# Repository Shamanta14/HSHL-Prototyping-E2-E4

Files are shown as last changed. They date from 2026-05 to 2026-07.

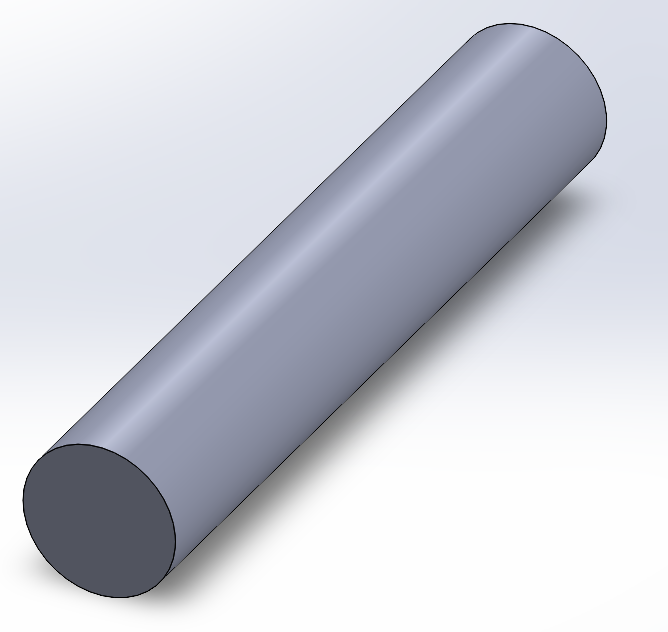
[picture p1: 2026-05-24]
CAD_Designs /CAD_Designs/GearMotor_Holder/Locking_Pin.png

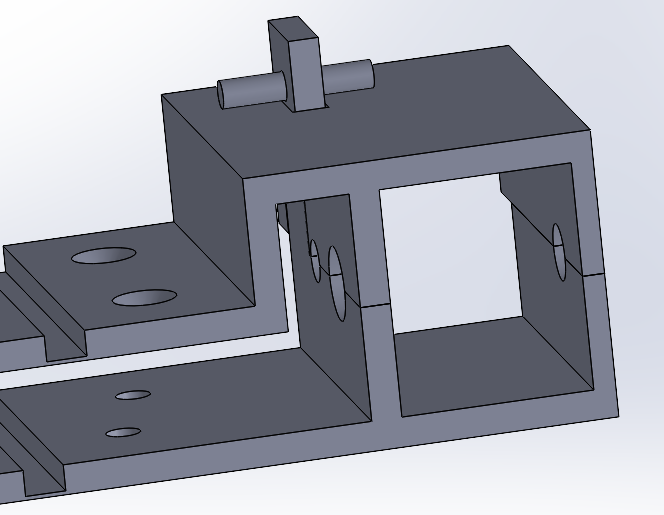
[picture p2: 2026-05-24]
CAD_Designs /CAD_Designs/GearMotor_Holder/Assembly_Motor_Holder.png

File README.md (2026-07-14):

# HSHL-Prototyping-E2-E4
Design and construction of an autonomous vehicle.

## Aim and objective 
The goal of this project is to design and prototype an autonomous robot capable of:
- Following a predefined track using line detection sensor.
- Detecting and avoiding obstacles in real time .
- Operating on a battery‑powered system with PWM speed control.

  ## System overview
  The autonomous robot integrates multiple subsystems:
- **IR sensors** detect line and provide feedback for track following control.
- **Ultrasonic sensors** measure distance to obstacles and trigger avoidance maneuvers when necessary.
- **The motor driver** controls direction and speed using PWM signals.
- Power is supplied by a 11,1 battery through a push on/off switch.

## Bill of material 

| Component | Quantity |
|---|---|
| Arduino Uno | 1 |
| Hobby Gearmotor | 2 |
| IR Sensor | 2 |
| Ultrasonic Sensor (4‑pin) | 2 |
| 9V Battery | 1 |
| Slide Switch | 1 |

### Repository Structure

| Folder Name | Description |
|---|---|
| CAD_Designs/CAD_Designs  | Contains 3D models and mechanical design files for the robot chassis. |
| Main_Robot_Project | Includes Arduino code, wiring diagrams, and main logic implementation. |
| Sensors_Datasheets | Datasheets for IR and Ultrasonic sensors used in the project. |
| Sensors_Testing | Test results and calibration data for sensor performance. |
| System&UML_diagrams | UML diagrams and system architecture documentation. |
| README.md | Project overview and documentation. |

## Contributors 
Project by Team E2-E4
-
-
-
-
Hochschule Hamm Lippstadt

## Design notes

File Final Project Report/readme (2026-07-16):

## Project Report

The complete project report documents the design, implementation, testing, and evaluation of the autonomous vehicle.

The report covers the following main topics:

- Background, problem statement, project goals, and constraints
- System design and engineering approach
- System architecture, data flow, and UML diagrams
- Hardware components, electrical connections, and mechanical design
- Software architecture, PID control, and obstacle avoidance
- Simulation, testing, verification, and performance evaluation
- Challenges, current limitations, and future improvements
- Team contributions, conclusion, and lessons learned

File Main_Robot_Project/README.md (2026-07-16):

## Track following robot.
-> Battery-powered system with a slide switch.

-> PWM (Pulse Width Modulation) Speed Control using analogWrite() for the Gearmotor speed.

-> Two Ultra Sonic Sensor detects the presence of an obstacle within a specified threshold distance.

## Detection threshold 
   Any object detected at or below the specified threshold distance will be considered as "Detected".

   Else "Not Detected".

->The Two IR sensor detect the presence of the track.

## IR sensor reading 

   LOW (0) when detecting black track

   HIGH (1) when detecting white surface

## System Behaviour 

-> The robot moves forward only when it is on the track and there is no obstacle ahead.

-> If the robot moves away from the track, it automatically self-corrects its position

   and continues moving along the track.

-> If an obstacle is detected ahead within the threshold distance, the robot stops moving.

## Bill of material

| Component |Quantity |
|---|---|
| Arduino Uno | 1 |
| Hobby Gearmotor | 2 |
| IR Sensor | 2 |
| Ultrasonic Sensor (4‑pin) | 2 |
| 9V Battery | 1 |
| Push on/off Switch | 1 |

 ## Repository Structure

| Folder/File | Description |
|---|---|
| Assembled Parts | Mechanical assembly files for robot chassis |
| Motor Driver | Code for PWM motor control |
| Sensors Code Function | Functions for IR,ultrasonic sensors and motor. |
| Tinkercad_circuitwiring  | Circuit wiring diagrams |
| Code.cc | Main Arduino logic implementation |
| Pin_Connections.h | Pin mapping for sensors and motors |
| README.md | Project documentation |

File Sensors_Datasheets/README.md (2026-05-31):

# Components Datasheets

This folder contains the datasheets for all major electronic components used in the autonomous robot project.  
Each datasheet provides essential technical information such as:

- Electrical characteristics  
- Pin configurations  
- Operating voltages  
- Timing diagrams  
- Mechanical dimensions  
- Usage guidelines  

These documents are critical for correct system design, wiring, and integration of the robot’s hardware components.

## Repository Structure

| File/Folder Name | Description |
|---|---|
| Arduino_Uno_Datasheet.PDF | Datasheet for Arduino Uno microcontroller board |
| IR_Sensor-Datasheet.pdf | Datasheet for IR sensor used in line detection |
| L298N Motor Driver Datasheet.pdf | Datasheet for L298N motor driver IC |
| Ultra_Sonic_Sensor(4-pins)_Datasheet.pdf | Datasheet for HC‑SR04 ultrasonic distance sensor |
| README | Documentation describing component datasheets usage |

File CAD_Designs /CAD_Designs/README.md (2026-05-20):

## CAD Designs-Prototype 

This folder contains all 3D‑designed holders required for the HSHL Prototyping project.
Each holder was modeled with correct tolerances, print‑ready geometry, and mounting features suitable for laser‑cut or 3D‑printed chassis integration.

## Included components 
## Motor holder 
-Designed to secure the DC motor firmly during motion.

-Includes side walls and a base slot for stability.

-Mounting holes added for attachment to the chassis.

-Clearance added to prevent vibration and friction.

## IR-sensor holder 
-Tolerances applied (0.3–0.5 mm) to ensure smooth insertion.

-Side guides prevent sensor wobbling.

-Front opening allows unobstructed IR transmission.

## UR-sensor holder 
-Dual‑eye cutouts for the ultrasonic transducers.

-PCB support rails included to hold the board in place.

-Mounting tabs added for chassis attachment.

-Fully closed geometry for 3D printing.

## Battery and Breadboard Holder 
-Compartment designed to hold the battery pack securely.

-Separate platform for the mini breadboard.

-Cable‑routing slots included for clean wiring.

-Reinforced walls for durability.

## Tools Used 
- Solid was used to design the parts.
  
- Bambu studio used to generate the simulation for the 3D printing

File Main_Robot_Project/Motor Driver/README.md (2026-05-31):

Tinkercad Motor Driver Test:

Testing the following components together:

-> Two gear motors -> One slide switch -> One Motor Driver(L293D)

The system is powered using a 9V battery with a slide switch for power control.

The Enable1&2 and Enable3&4 pins of motor driver are connected to Arduino pins 6 and 9. Because they are PWM pins which can be used to control the motor speed.

The Input pins 1,2,3 and 4 are connected to Arduino pins 3,2,12 and 13 respectively. These Input pins can be used to control the motor direction.

The purpose of this testing is to verify that the motor driver can control the speed and direction of the gear motors, as well as stop and start them flexibly.

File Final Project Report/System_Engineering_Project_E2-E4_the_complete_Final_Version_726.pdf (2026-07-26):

## Design and Development of an Autonomous Mobile Robot with PID-Based Line Following and Obstacle Avoidance

Xintong Feng, Shamanta Islam, Paula Cho, Elvis-Ledoux

Systems Engineering Project Group E2–E4
Hochschule Hamm-Lippstadt (HSHL)

Abstract— This project presents the design and development of an autonomous mobile robot capable of line following and obstacle avoidance. The system integrates an Arduino Uno, infrared sensors, ultrasonic sensors, DC motors, and PID-based control to achieve reliable navigation on a predefined track. The robot was designed, simulated, assembled, and tested to evaluate sensor performance, motor control, and overall system reliability. Experimental results demonstrate successful line tracking, obstacle detection, and autonomous manoeuvring, while highlighting opportunities for future improvement in adaptive obstacle avoidance.

Keywords—Autonomous mobile robot, line following, obstacle avoidance, PID control, infrared sensors, ultrasonic sensors, Arduino Uno.

### 1. Introduction and Objectives

### 1.1 Background

Autonomous vehicles have become an important topic in robotics because they can perform tasks with little or no human intervention. One common example is a line-following robot, which uses sensors to detect and follow a predefined path. Such robots are widely used in warehouses, factories, and automated production systems to transport materials efficiently while reducing manual work. Because of their practical applications, line-following robots are often used in educational projects to study embedded systems, sensor integration, and motor control.

### 1.2 Problem Statement

Line-following robots often struggle to maintain accurate tracking, especially during sharp turns, under inconsistent lighting conditions, or when unexpected obstacles appear on the path. This project addresses the challenge of designing a small autonomous vehicle that can reliably follow a black line while detecting obstacles, performing avoidance manoeuvres, and returning to the original track.

### 1.3 Project Goal

The goal of this project is to design and build an autonomous mobile robot capable of navigating a predefined track while demonstrating basic autonomous behaviour through line following and obstacle avoidance.
The specific objectives of this project are:
- Design and construct an autonomous vehicle.
- Follow a predefined black line.
- Detect obstacles.
- Perform an obstacle-avoidance manoeuvre and safely return to the original track.
- Control the DC motors.
- Integrate all hardware and software components into one complete system.
- Test and evaluate the prototype under different operating conditions.

### 1.4 Project Constraints

- The robot must be built using low-cost components, including an Arduino Uno R3, IR sensors, ultrasonic sensors, and simple DC motors.
- The system operates on battery power, which limits runtime and requires efficient motor control.
- IR and ultrasonic sensors have limited range and accuracy, especially under varying lighting and surface conditions.
- The robot must navigate a predefined track containing curves and obstacles using PWM and PID-based control.
- Development and testing must be completed within the course timeframe.

### 2. System Design and Engineering Approach

### 2.1 Design Approach

The system was designed using a top-down modular approach. We first defined the overall system architecture and then decomposed it into four major subsystems. Each subsystem was assigned a specific functional responsibility to ensure a clear structure, straightforward integration, and reliable operation.

### 2.2 System Architecture Overview

The autonomous robot consists of four interconnected subsystems:
- Power Subsystem
- Sensor Subsystem
- Control Subsystem
- Motor Subsystem

The functional requirements of each subsystem are listed below.
- Power Subsystem: Supplies stable voltage and current.
- Sensor Subsystem: Detects environmental changes and generates measurement signals.
- Control Subsystem: Processes sensor measurements and produces control commands.
- Motor Subsystem: Converts control commands into mechanical motion.

Together, these subsystems fulfil the functional requirements of the autonomous robot, with each subsystem performing a specific role in the overall operation of the system.

### 2.3 System Data Flow

The autonomous robot operates through a continuous flow of electrical signals and power between the four subsystems.
- Sensor Subsystem → Control Subsystem

– IR sensors send digital signals indicating whether the robot is on the line.
– Ultrasonic sensors send distance measurements for obstacle detection.
- Control Subsystem → Motor Subsystem

– The Arduino processes sensor inputs and determines whether the robot should move forward, turn, stop, or

avoid obstacles.
– PWM signals and direction commands are generated for the motor driver.
- Motor Subsystem → Mechanical Motion

– The motor driver amplifies the control signals and drives the DC motors.
– The motors perform the required movements (forward, left, right, and stop).
- Power Subsystem → All Subsystems

– The battery supplies stable voltage to the Arduino, sensors, motor driver, and motors.
– Continuous power enables sensing, control, and actuation.

This data flow enables all subsystems to operate together, allowing the robot to achieve reliable line following and obstacle avoidance.

### 3. System and UML Diagrams

To support the development of the autonomous vehicle, a set of system and UML diagrams was created to model the architecture, behaviour, and interactions within the system. These diagrams provide a structured understanding of how the robot operates, how its subsystems communicate, and how the control logic responds to sensor inputs.

### 3.1 Block Definition Diagram

Figure 1 shows the main hardware subsystems of the robot and their relationships. The system consists of four main parts: the power supply, sensing, control, and driving subsystems. The sensing subsystem includes the IR and ultrasonic sensors, the control subsystem contains the Arduino Uno, and the driving subsystem consists of the motor driver and DC motors. The wheel assembly is shown separately as a mechanical component.

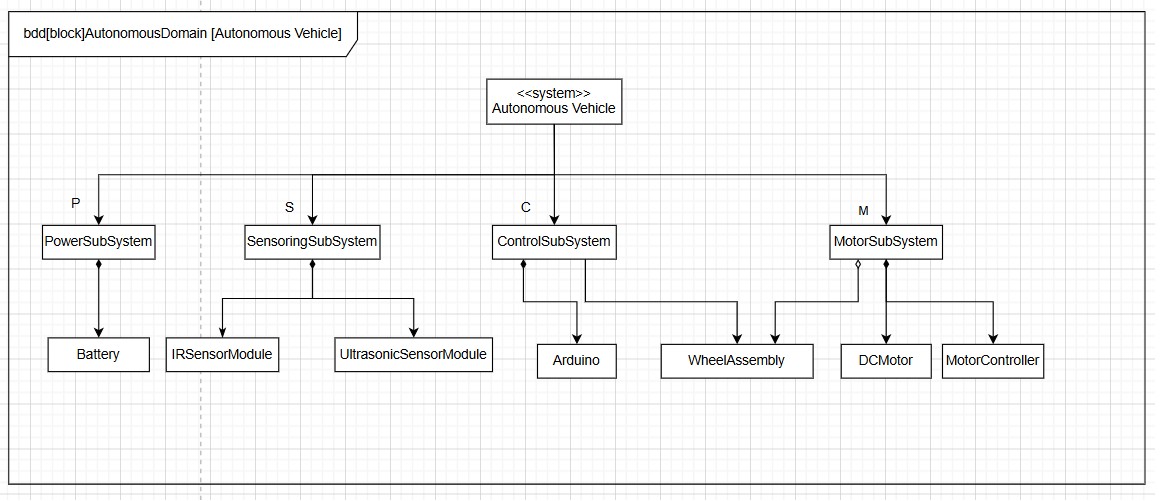
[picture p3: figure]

Fig. 1. Block Definition Diagram

### 3.2 Internal Block Diagram

Fig. 2 shows the internal connections between the robot subsystems. The power subsystem supplies the Arduino Uno, while the sensing subsystem contains the IR and ultrasonic sensors connected to it. Based on the sensor data, the Arduino sends control commands to the motor driver, which drives the DC motors. The diagram shows how power, sensor data, and control signals flow through the system.

### 3.3 Activity Diagram

Fig. 3 shows the swimlane-based workflow of the autonomous vehicle. It is divided into four swimlanes: IR sensors, ultrasonic sensors, controller, and drive motors.
The swimlanes show which system component performs each activity, while the decision nodes show how the controller selects PID line following, obstacle bypass, or a 180-degree

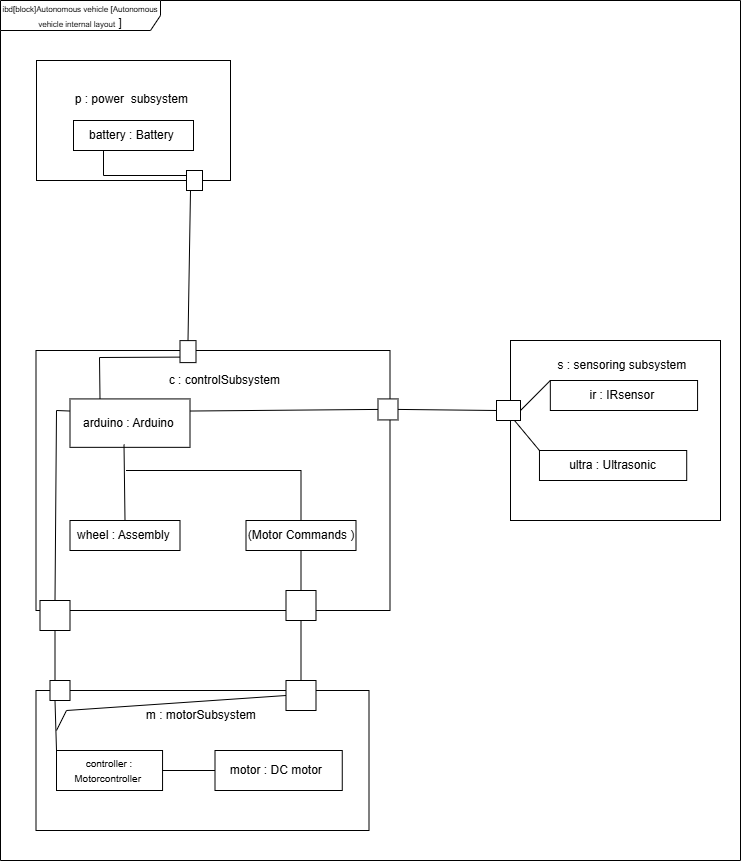
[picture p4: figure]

Fig. 2. Internal Block Diagram

U-turn. The arrows show the order of the activities and the flow between the four system components.

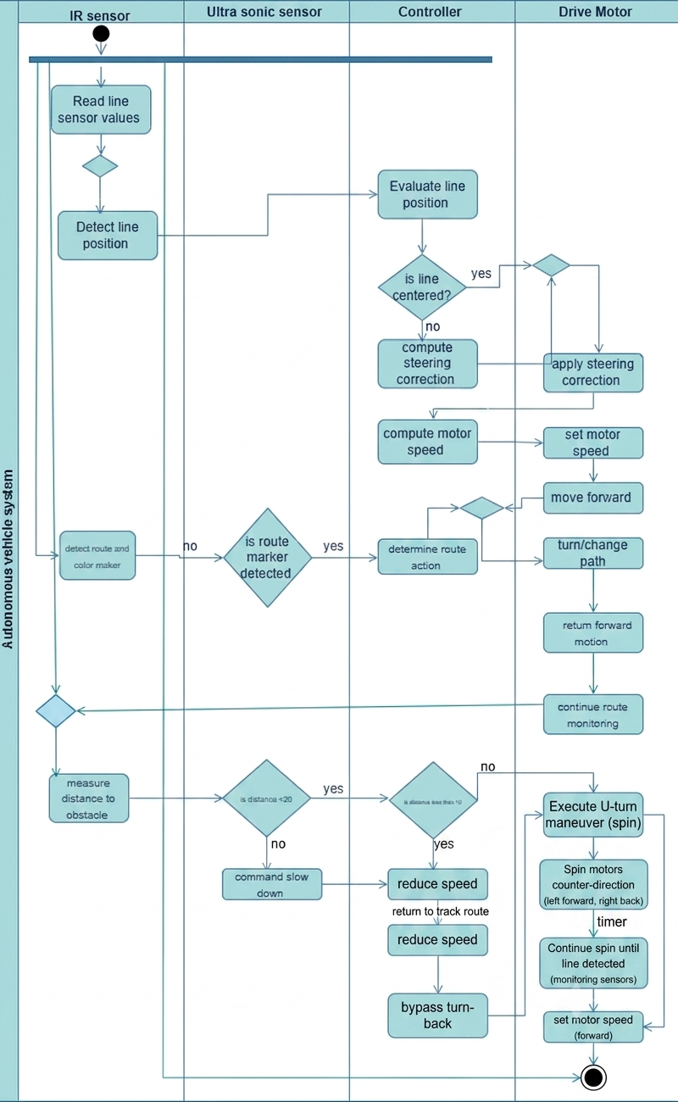
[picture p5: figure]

Fig. 3. Activity Diagram

### 3.4 Sequence Diagram

Fig. 4 shows the sequence diagram of the autonomous vehicle, including five lifelines: the IR sensors, Ultrasonic sensors, Arduino, motor driver, and DC motors. The messages are arranged from top to bottom in time order. The alt frame shows three cases: normal line following, first-obstacle bypass, and second-obstacle 180-degree U-turn. The loop frame shows that the process repeats continuously.

### 3.5 Use Case Diagram

Fig. 5 shows the main functions of the autonomous vehicle control software. The diagram includes line following, route navigation, obstacle avoidance, stopping, and performing a U-turn. The include and extend relationships show how these functions are connected and under which conditions they are

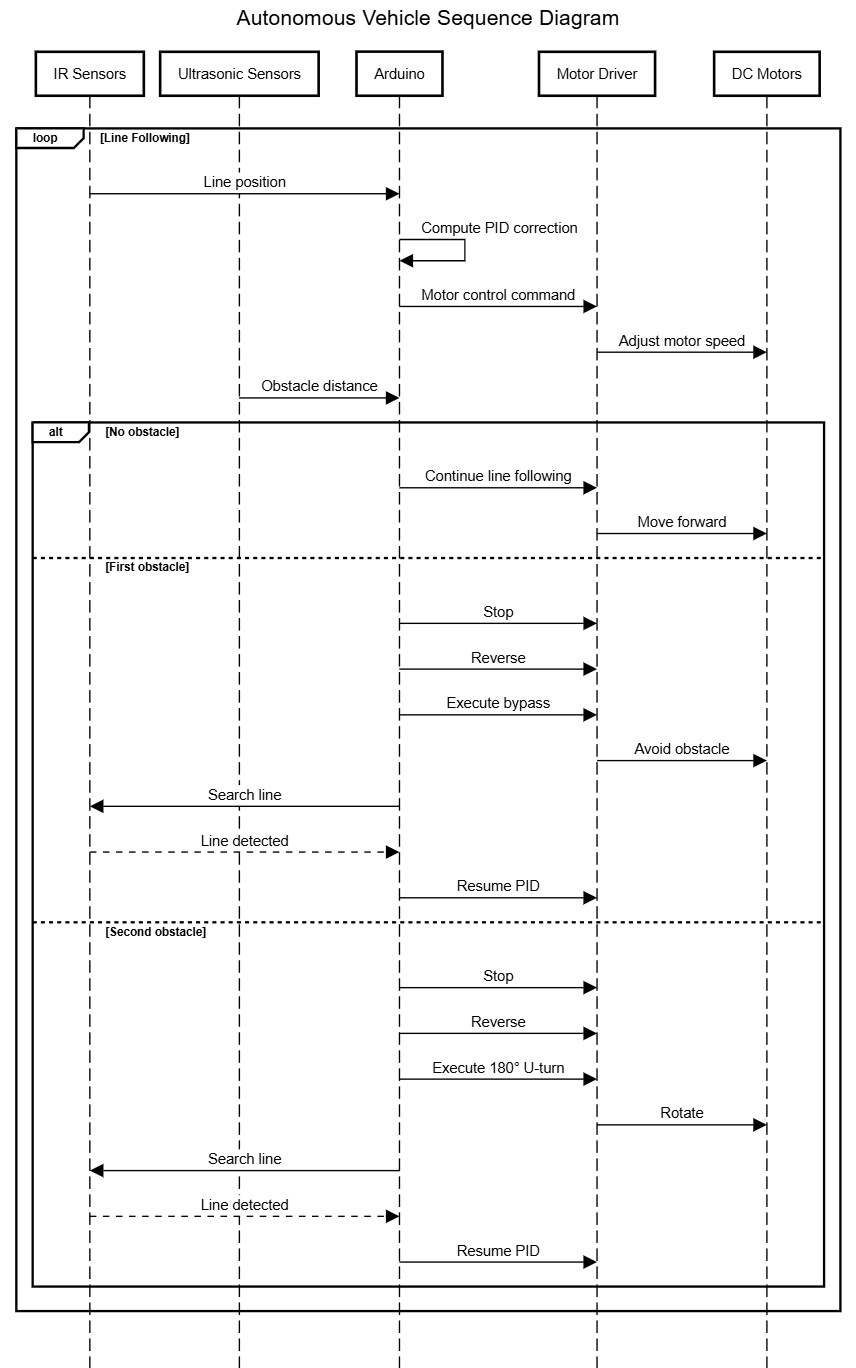
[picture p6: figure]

Fig. 4. Sequence Diagram

executed.

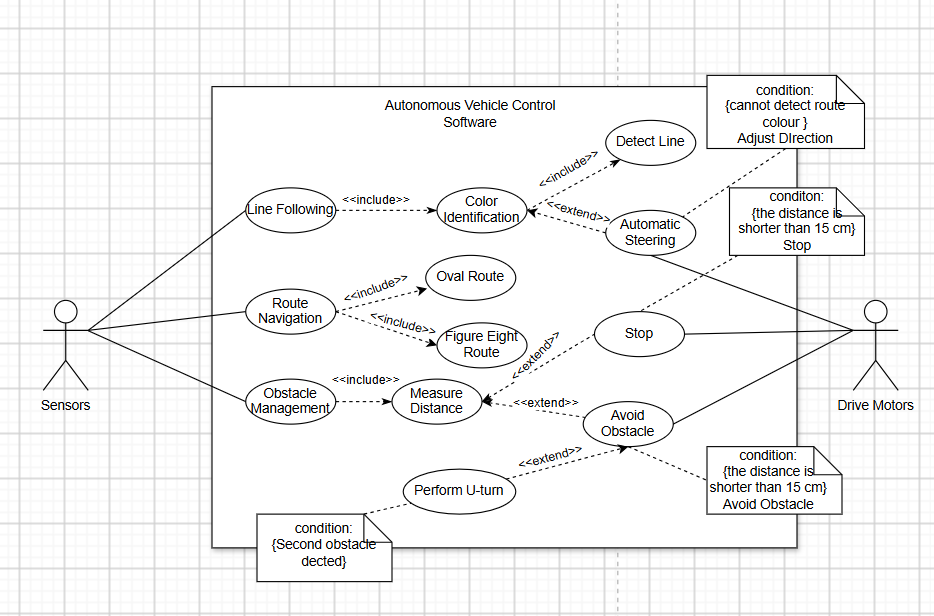
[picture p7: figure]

Fig. 5. Use Case Diagram

### 4. Risk and Mitigation

Table 1 summarises the potential risks encountered during the project and the actions taken to minimise these risks.

Risk Description | Mitigation Strategy
IR Sensor Misalignment or Inaccurate Line Detection | • Calibrate the IR sensors. • Adjust the sensor sensitivity.
Low Battery Voltage Affect-ing Motor Performance | • Check the battery before testing. • Replace it if necessary.
Hardware Damage | • Check all wires and components. • Secure all parts before testing.
Software or PID Problems | • Test each function separately. • Fine-tune the PID values. • Back up the code using GitHub.
Obstacle Avoidance Failure | • Test the ultrasonic sensors. • Adjust the delay and timeout values.

Table 1. Project Risks and Mitigation Strategies

### 5. Hardware Integration and Mechanical Design

### 5.1 Components

Table 2 lists the hardware components used in the autonomous vehicle. It presents the quantity and purpose of each component required for the assembly.

Component | Quantity | Purpose
Arduino Uno R3 | 1 | Main controller.
L298N Motor Driver | 1 | Motor control.
DC Motor | 2 | Drive the wheels.
Infrared Reflective Sensor | 2 | Detect the black line for line fol-lowing.
Ultrasonic Sensor HC-SR04 | 2 | Obstacle detection.
Battery | 1 | Power supply.
Chassis | 1 | Robot frame.
Wheel | 2 | Robot movement.
Push On/Off Switch | 1 | Turn the robot on and off.
Breadboard | 1 | Connect and organize the elec-tronic components.

Table 2. Components Used for Assembly

### 5.2 Connections

Figure. 6 illustrates the wiring connections of the autonomous vehicle. It shows how the Arduino Uno is connected to the motor driver, sensors, battery, and other hardware components together with their pin assignments.

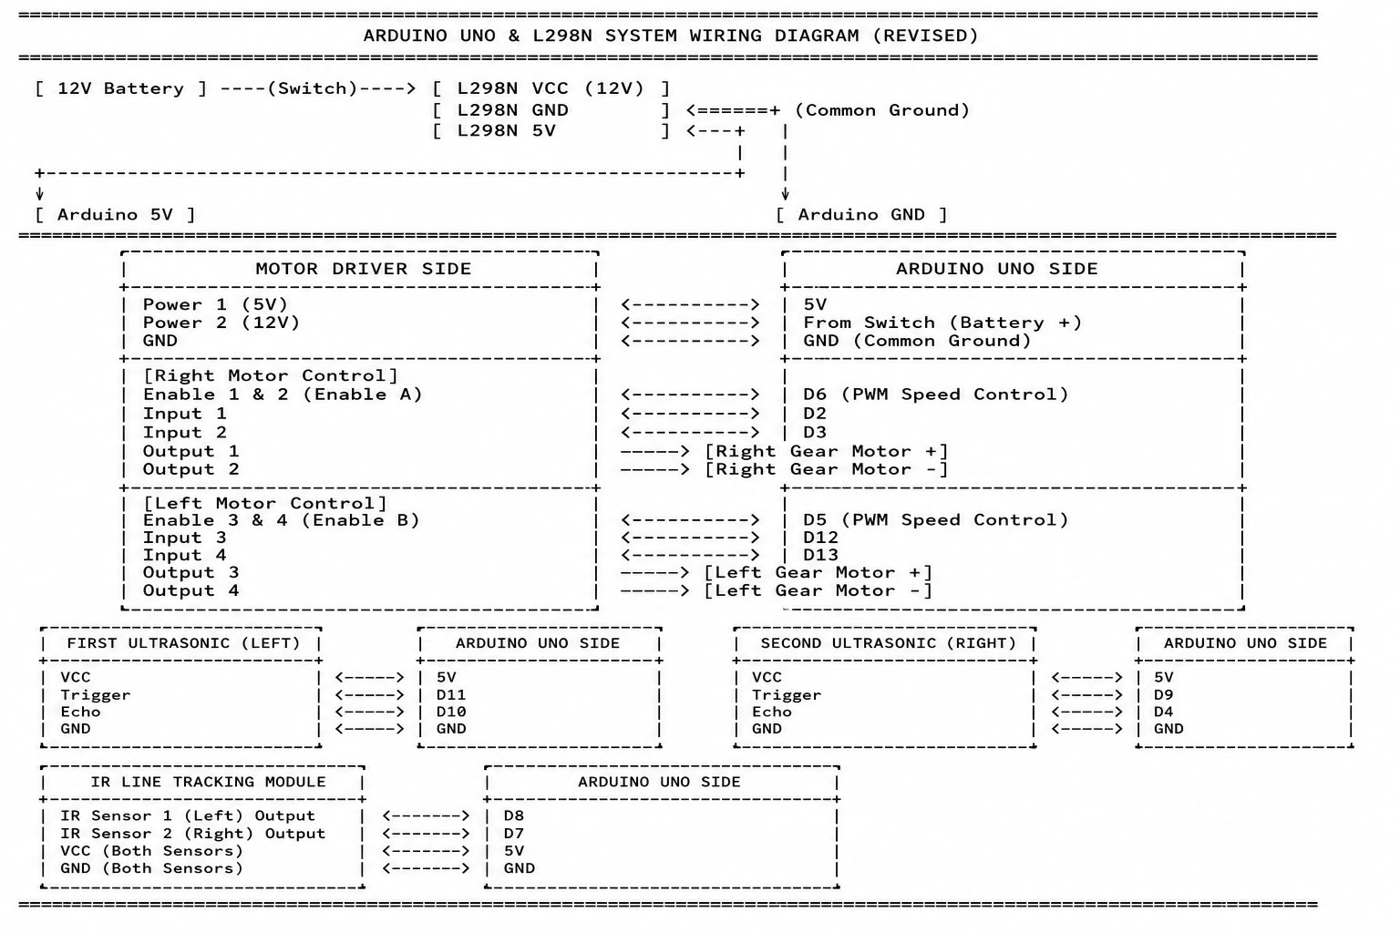
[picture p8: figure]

Fig. 6. Autonomous Vehicle Wiring Diagram

The motor speed is controlled through the PWM inputs (ENA and ENB) of the L298N motor driver [1].The Arduino Uno provides six PWM-capable digital pins (D3, D5, D6, D9, D10, and D11), which are generated by three hardware timers. Timer0 controls pins D5 and D6, Timer1 controls pins D9 and D10, and Timer2 controls pins D3 and D11 [2].
In this project, the PWM inputs of the motor driver were connected to pins D5 and D6 because both pins are controlled by Timer0. This allowed both motor channels to share the same timer configuration, making it possible to adjust the PWM frequency of both motors by configuring only one timer. Otherwise, if ENA and ENB were connected to PWM pins controlled by different timers, each timer would need to be configured separately.
The Timer0 prescaler was modified in software to increase the PWM frequency, resulting in smoother motor operation and reduced audible motor noise. The motor speed was then adjusted independently by changing the PWM duty cycle, allowing accurate speed control during PID-based line following.
TCCR0B = TCCR0B & B11111000 | B00000010;

Since Timer0 is also used by Arduino timing functions, changing its prescaler affects the effective timing of delay() and millis(). Therefore, the delay and timeout values were adjusted through physical testing.

### 5.3 Mechanical Design

The holders were precisely designed and dimensioned using SolidWorks to ensure accurate fitting and stable mounting of each component.
Figure. 7 illustrates the placement of the 3D-printed holders on the robot chassis. The motor holders, ultrasonic sensor holders, IR sensor holder, and battery/breadboard holder are positioned to securely mount each component. The two IR sensors are mounted at the centre of the front of the chassis to improve black line detection and provide balanced feedback for accurate line-following.

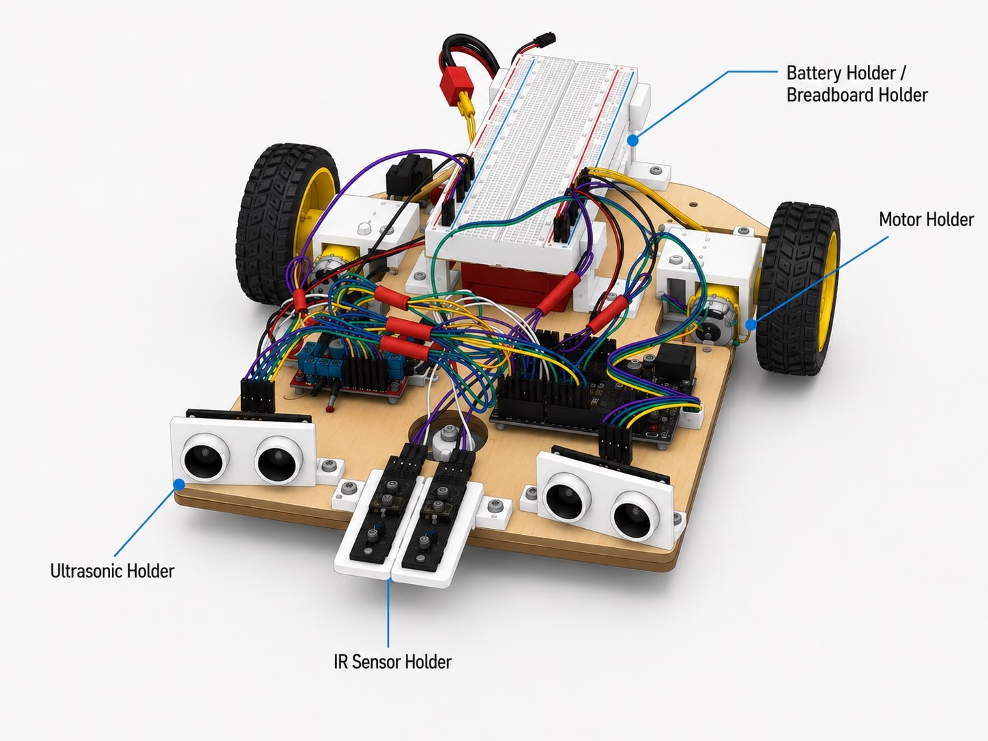
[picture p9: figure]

Fig. 7. Holder Placement on the Robot Chassis

### 6. Software Design

### 6.1 Control Logic

Fig. 8 shows the main control logic of the robot. Under normal conditions, the robot follows the black line using two IR sensors and a PID controller. When an obstacle is detected, the program checks how many obstacles have already been encountered. For the first obstacle, the robot performs a bypass manoeuvre. When the second obstacle is detected, the robot makes a 180° U-turn. After the obstacle-handling process is completed, the robot searches for the black line again and continues line following.

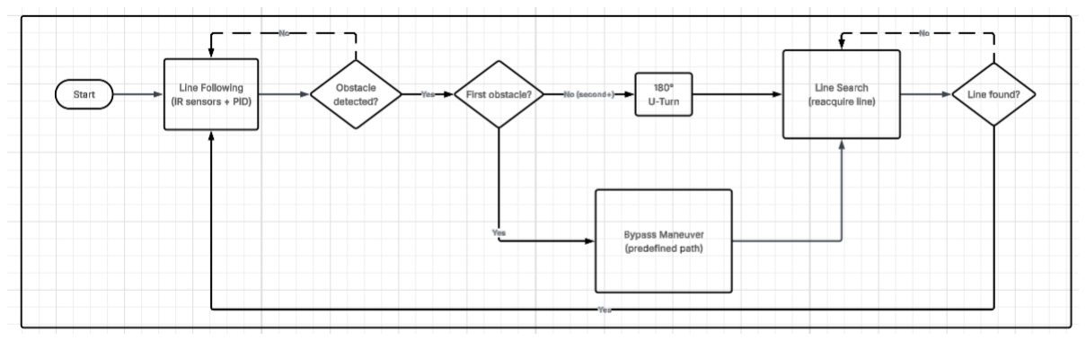
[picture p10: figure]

Fig. 8. Software Control State Diagram

### 6.2 Code Architecture

The software was divided into several functional modules, as summarised in Table 3. The setup() function initialises the sensors, motor driver, PWM configuration, and serial communication. The loop() function acts as the main control routine and continuously checks the sensor readings to determine the robot’s next action.
During normal operation, the pidLineFollow() function controls line following using the two IR sensors and the PID controller. When an obstacle is detected, the program selects either the first-obstacle bypass or the second-obstacle U-turn according to the value of the obstacle counter.
Module | Main Function(s) | Purpose
System Initialization | setup() | Initialises the IR sensors, ultrasonic sensors, motor-driver pins, PWM settings, and serial communication. It also stops both motors before the robot starts moving.
Sensor Processing | getDistance() readSensor Filtered() | Measures the distance between the robot and an obstacle using the ultrasonic sensors. Measures the distance between the robot and an obstacle using the ultrasonic sensors. It also reads the digital signals from the two IR sensors and helps reduce unstable readings caused by shadows and reflections.
Decision Making (Main Control Logic) | loop() | Continuously checks the sensor readings and selects one of three operating modes: normal PID line following, first-obstacle bypass, or second-obstacle 180-degree U-turn.
PID Line-Following Control | pidLineFollow() resetPID() | Calculates the PID correction and adjusts the left and right motor speeds to keep the robot on the black line. The PID values are reset after an obstacle-handling manoeuvre.
First-Obstacle Bypass | avoidTurnLeft() avoidTurnRight() setMotors() | Executes the bypass sequence for the first obstacle. The robot reverses, turns away from the line, moves around the obstacle, and turns back until the black line is detected again.
Second-Obstacle U-Turn | spinRight() setMotors() | The spinRight() function drives the two motors in opposite directions to perform an in-place 180-degree U-turn. It continues rotating until one of the IR sensors detects the black line again.
Motor Control | setMotors() stopMotors() avoidTurnLeft() avoidTurnRight() spinRight() | Controls the direction and PWM speed of both motors. These functions provide forward motion, reverse motion, curved turning, in-place rotation, and stopping.

Table 3. Software Modules and Main Functions

### 6.3 PID Controller

To achieve smooth and accurate line following, a PID (Proportional–Integral–Derivative) controller was implemented. The controller adjusts the speeds of the left and right motors according to the line-tracking error detected by the infrared sensors. The implemented controller follows the classical PID control law [3],p. 314:

u(t) = Kpe(t) + Ki

∫
e(t) dt + Kd

de(t)

dt

where u(t) represents the control output, e(t) is the tracking error, and Kp, Ki

, and Kd are the proportional, integral, and derivative gains, respectively. In the implemented controller, the parameters were set to Kp = 80.0, Ki = 0.3, and Kd = 20.0. The proportional term reacts to the current error, the integral term is implemented by accumulating the tracking error, and the derivative term is calculated from the difference between the current and previous errors, helping to reduce oscillation.

Left Sensor | Sensor Right | Error | Motor-Speed Adjustment | Robot Motion
1 | 1 | 0 | vleft = vbase , vright = vbase | Move forward
1 | 0 | −1 | vleft = vbase − u(t), vright = vbase + u(t) Since u(t) < 0, the left motor is faster. | Turn right
0 | 1 | +1 | vleft = vbase − u(t), vright = vbase + u(t) Since u(t) > 0, the right motor is faster. | Turn left
0 | 0 | ±1.5 | The motor speeds are adjusted according to the last detected line direction. | Search for line

Table 4. PID-Based Line-Following Logic

When both sensors detect the black line, the error and PID output are zero, so both motors run at the base speed and the robot moves forward. If only the left sensor detects the line, the error is negative. The left motor becomes faster and the right motor becomes slower, causing the robot to turn right. If only the right sensor detects the line, the error is positive. The right motor becomes faster and the left motor becomes slower, causing the robot to turn left.
When neither sensor detects the black line, the robot uses the stored lastDirection value to determine the search direction. The value is set to 0 when both sensors detect the black line (L = 1, R = 1), to 1 when only the left sensor detects the line (L = 1, R = 0), and to 2 when only the right sensor detects the line (L = 0, R = 1).
If both sensors detect the white surface (L = 0, R = 0), the stored value is used to calculate the error. If lastDirection = 1, the error is set to −1.5. If lastDirection = 2, the error is set to +1.5. If lastDirection = 0, the error is set to 0. The motor speeds are then adjusted so that the robot searches for the black line again.

### 6.4 Obstacle Avoidance Software Implementation

The obstacle avoidance program was developed incrementally through repeated physical tests.
To implement obstacle avoidance, separate movement functions were created based on the setMotors() function. These functions control the direction and speed of the two motors, making each movement easier to test and adjust.
For the first obstacle, the robot first moves backward with a PWM value of 160. It then turns left using a PWM value of 40 for the left wheel and 170 for the right wheel.
After the left turn, both motors run at a PWM value of 100 for 20 ms. The program then checks whether both IR sensors have left the black line using the condition
LEFT_SENSOR == 0 && RIGHT_SENSOR == 0.
This condition is essential. Without it, the following forward movement and right-turn movement cannot be executed correctly. Once the condition is satisfied, the robot moves forward beside the obstacle with a PWM value of 160.
After passing the obstacle, the motor speeds change to PWM values of 40 and 170, causing the robot to turn right and search for the black line again. A while loop continuously checks the right IR sensor until the line is detected. Since the turning command is issued before the loop, the motor driver retains the assigned motor directions and PWM values while the sensor is checked. A timeout of 6000 ms prevents the loop from running indefinitely.
For the second obstacle, the robot first moves backward with a PWM value of 160 and then performs an in-place 180-degree

U-turn using spinRight(200). After an initial rotation of 1000 ms, both IR sensors are checked until either sensor detects the black line again or the 4000 ms timeout is reached.
After each obstacle-avoidance sequence, the PID controller is reset and the stored line direction is cleared before normal line following resumes. The movement speeds, delays, and timeout values were determined experimentally through repeated physical tests.

### 7. Simulation and Testing Results

At the beginning of the project, Tinkercad simulations were designed and performed to verify the circuit connections and identify potential errors before assembling the physical hardware.
After completing the individual component tests, a full Tinkercad simulation (Fig. 9) of the entire system was developed to verify that all components operated together as intended.

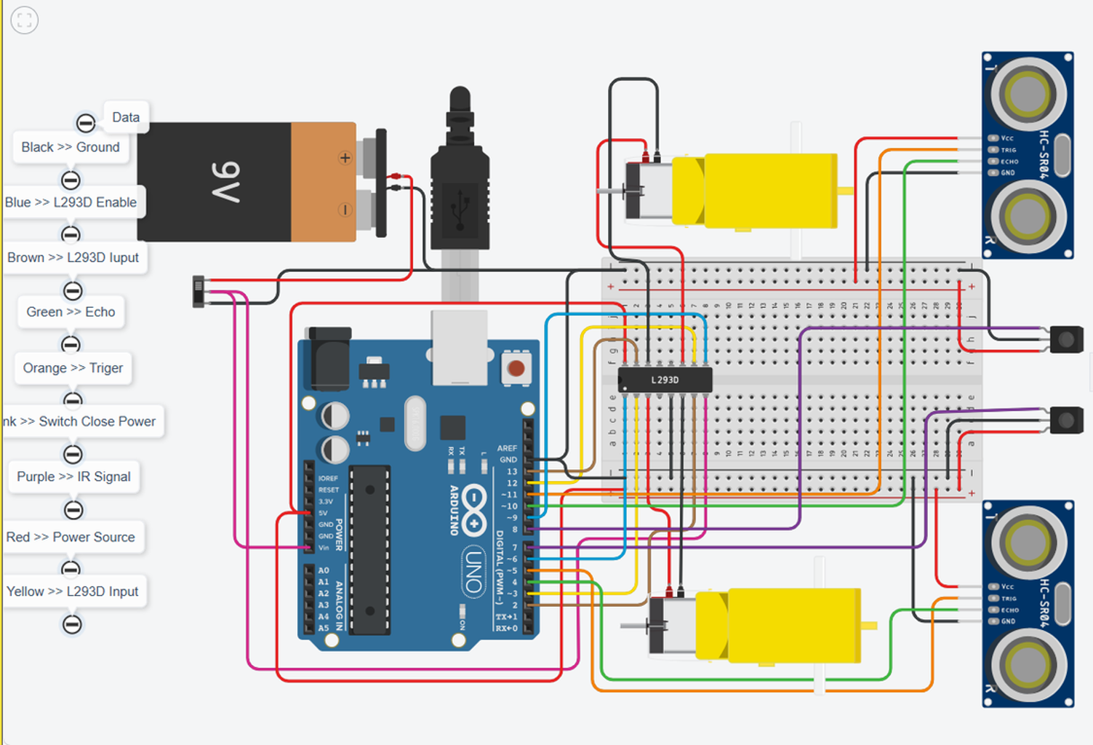
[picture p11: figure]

Fig. 9. System Wiring Diagram

### 7.1 System Verification Matrix

Table 5 summarises the verification results by listing the system requirements, verification methods, and test outcomes.

System Requirement | Verification Method | Pass/Fail
Follow predefined black track | Physical track test | PASS
Detect obstacle within 15 cm | Distance calibration in code | PASS
Execute obstacle bypass manoeuvre | Integrated track test | PASS
Execute second-obstacle 180◦ U-turn | Integrated track test | PASS
Battery runtime > 30 min | Endurance test | PASS

Table 5. System Verification Matrix

### 7.2 Performance Evaluation

After implementing the line-following and obstacle-avoidance functions, three experimental trials were conducted to evaluate the robot’s performance. The results are summarized in Table 6. The robot successfully completed the line-following task in all trials without deviating from the line. In addition, the robot detected every obstacle during testing. Although one collision occurred, the robot successfully avoided the obstacle in two of the three trials. These results demonstrate that the robot provides reliable line-following performance and generally effective obstacle avoidance, while further improvements could increase the consistency of obstacle avoidance.

Line Following Test
Trial | Path Completed | Time (s) | Line Deviation
1 2 3 | Yes Yes Yes | 47 40 33 | No No No

Obstacle Avoidance Test
Trial | Obstacle Detected | Collision | Obstacle Avoided
1 2 3 | Yes Yes Yes | No Yes No | Yes No Yes

Table 6. Performance Evaluation Results

### 8. Challenges, Limitations and Future Improve-

ments

### 8.1 Challenges and Solutions

During the development of the autonomous mobile robot, several challenges were encountered. The major issues and the corresponding solutions are summarised in Table 7.

Challenge | Description | Solution
Damaged Motor | The wiring of the right motor became disconnected, causing the motor to stop functioning. | Repaired and re-secured the motor wiring.
Damaged IR Sensor | The left IR sensor failed two weeks before the demonstration. The fault was identified when the robot could not perform left turns correctly. | Replaced the faulty IR sensor and recalibrated the system.
Line Deviation on Sharp Turns (Wiggling) | The robot deviated from the line during sharp turns because the steering response was unstable. The motors over-corrected left and right, causing the robot to drift off the line. | Implemented and tuned PID control by adjusting Kp and Kd. This eliminated wiggling and ensured smooth, accurate line-following during sharp turns.

Table 7. Challenges Encountered and Solutions

### 8.2 Current Limitations

Currently, the robot avoids obstacles by using predefined delay and timeout values. These parameters perform well in the current test environment but cannot guarantee successful obstacle avoidance under all conditions. Obstacles located at different positions or orientations may require further adjustment of the control parameters.

### 8.3 Future Improvements

A possible improvement is to install an additional ultrasonic sensor on the right side of the robot. By introducing a distance threshold instead of relying primarily on fixed delay values, the robot could adapt to obstacles at different positions and achieve more reliable obstacle avoidance.

### 9. Commits and Team Members Contributions

(GitHub)

As shown in Fig. 10 and Table 8, the team contributions were tracked using Git commit history.

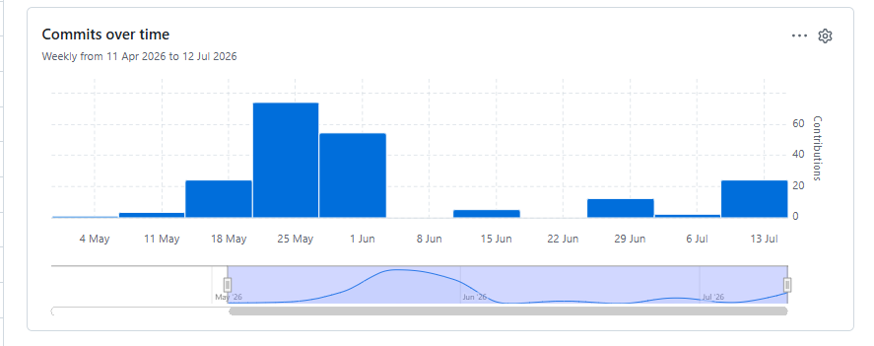
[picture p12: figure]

Fig. 10. Git Commit History

Team Member | Commits
Xintong Feng | 54
Shamanta Islam | 25
Elvis-Ledoux | 66
Paula Cho | 54
Total | 199

Table 8. Team Contribution Summary

### 10. Conclusion

The autonomous vehicle prototype successfully demonstrated reliable line following and obstacle avoidance using low-cost hardware and PID-based control. Through systematic design, modular implementation, and iterative testing, the robot achieved stable navigation and consistent performance on the predefined track.
In addition to accurate line tracking, the robot was able to detect, avoid, and manoeuvre around obstacles, proving the effectiveness of the implemented control logic. Overall, this project represents a complete design process from initial concept to real-world implementation, combining both hardware and software development into a functional autonomous system.

### 11. Lessons Learned

- We learned that good communication and clear task division are important in a team project.
- Some faults were not obvious, so we had to check each part carefully and step by step. This improved our troubleshooting skills.
- This project improved our understanding and confidence in working with both hardware and software.

References

[1] Handson Technology, “L298N Dual H-Bridge Motor Driver User Guide,” [Online]. Available: https://www.handsontec.com/dataspecs/module/L298N%20Mo tor%20Driver.pdf. (https://www.handsontec.com/dataspecs/module/L298N%20Motor%20Driver.pdf) [Accessed: Jul. 16, 2026].
[2] Arduino, “UNO R3,” Arduino Documentation. [Online]. Available: https://docs.arduino.cc/hardware/unorev3/. [Accessed: Jul. 16, 2026].
[3] J. Wilkie, M. Johnson, and R. Katebi, Control Engineering: An Introductory Course. Basingstoke, U.K.: Palgrave Macmillan, 2002.
[4] Shamanta14, | “HSHL-Prototyping-E2-E4: | Design
and | Construction | of | an | Autonomous | Vehicle
That Can Follow a Line, Detect, and Avoid Obstacles,” GitHub repository. [Online]. Available: https://github.com/Shamanta14/HSHL-Prototyping-E2-E4. [Accessed: Jul. 16, 2026].

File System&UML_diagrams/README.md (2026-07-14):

##  System & UML Diagrams

This folder contains the Unified Modeling Language (UML) and system design diagrams used to represent the architecture, behavior, and interactions of the autonomous robot system.
These diagrams help visualize how different subsystems (hardware and software) communicate and function together.

## Purpose 
-The diagrams in this folder serve to:

-Illustrate system structure and component relationships.

-Define subsystem interactions and data flow.

-Document requirements and design logic.

-Support debugging, integration, and future scalability.

-Each diagram provides a unique perspective on the robot’s design — from high‑level architecture to detailed operational flow.

## Repository Structure

| File Name | Description |
|---|---|
| Activity_diagram2F.drawio.png | Activity diagram showing system workflow |
| BlockDefinitionDiagram.png | Block definition diagram outlining system blocks |
| Internal_blockdiagram.drawio.png | Internal block diagram showing component relations |
| Package Diagram.png | Package diagram representing module organization |
| Requirements Diagram.png | Diagram listing system requirements and dependencies |
| SMD_diagram.drawio.png | System modeling diagram for hardware/software mapping |
| Sequence Diagram.png | Sequence diagram illustrating event interactions |
| Use case (Xintong Feng).png | Use‑case diagram showing user interactions |
|Updated Diagram | The final version of Diagram after the completement of the project|

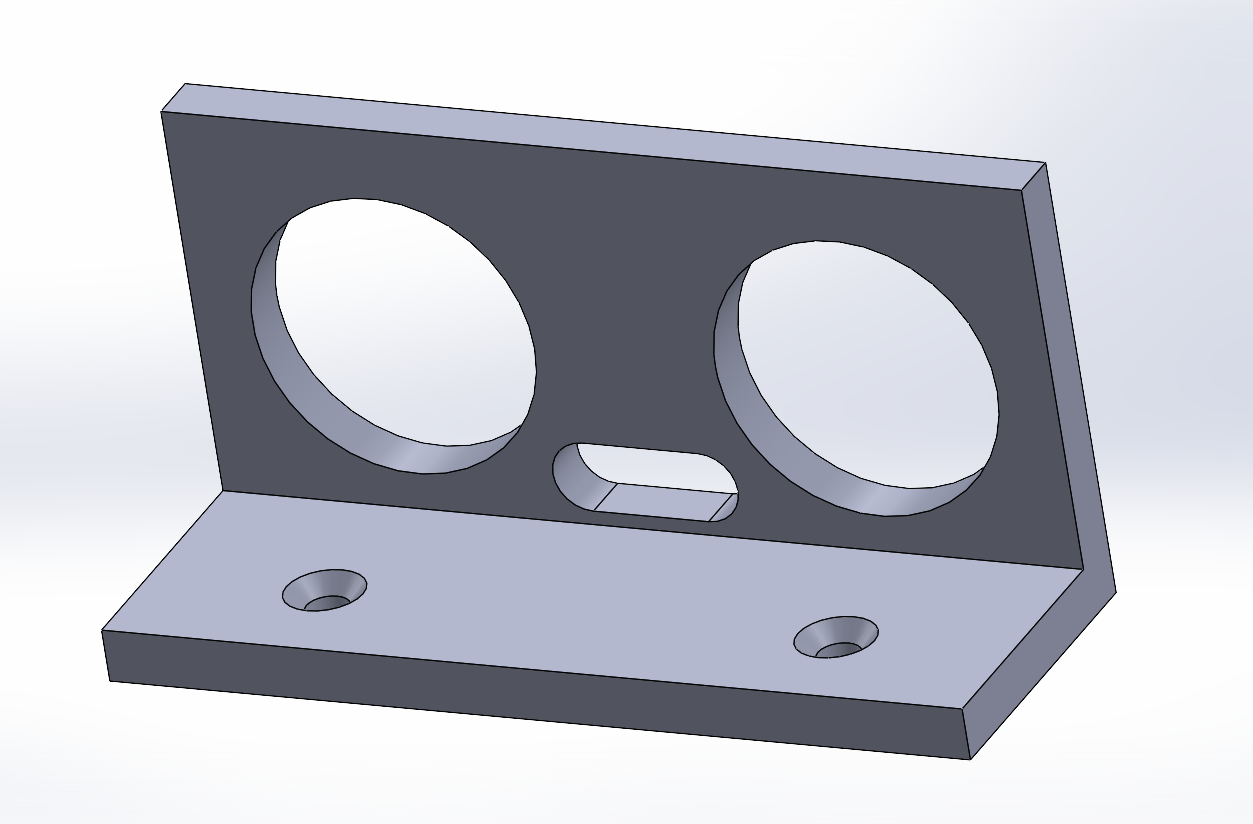
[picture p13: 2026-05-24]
CAD_Designs /CAD_Designs/Ultra_Sonic_Sensor_E-2_E4.PNG

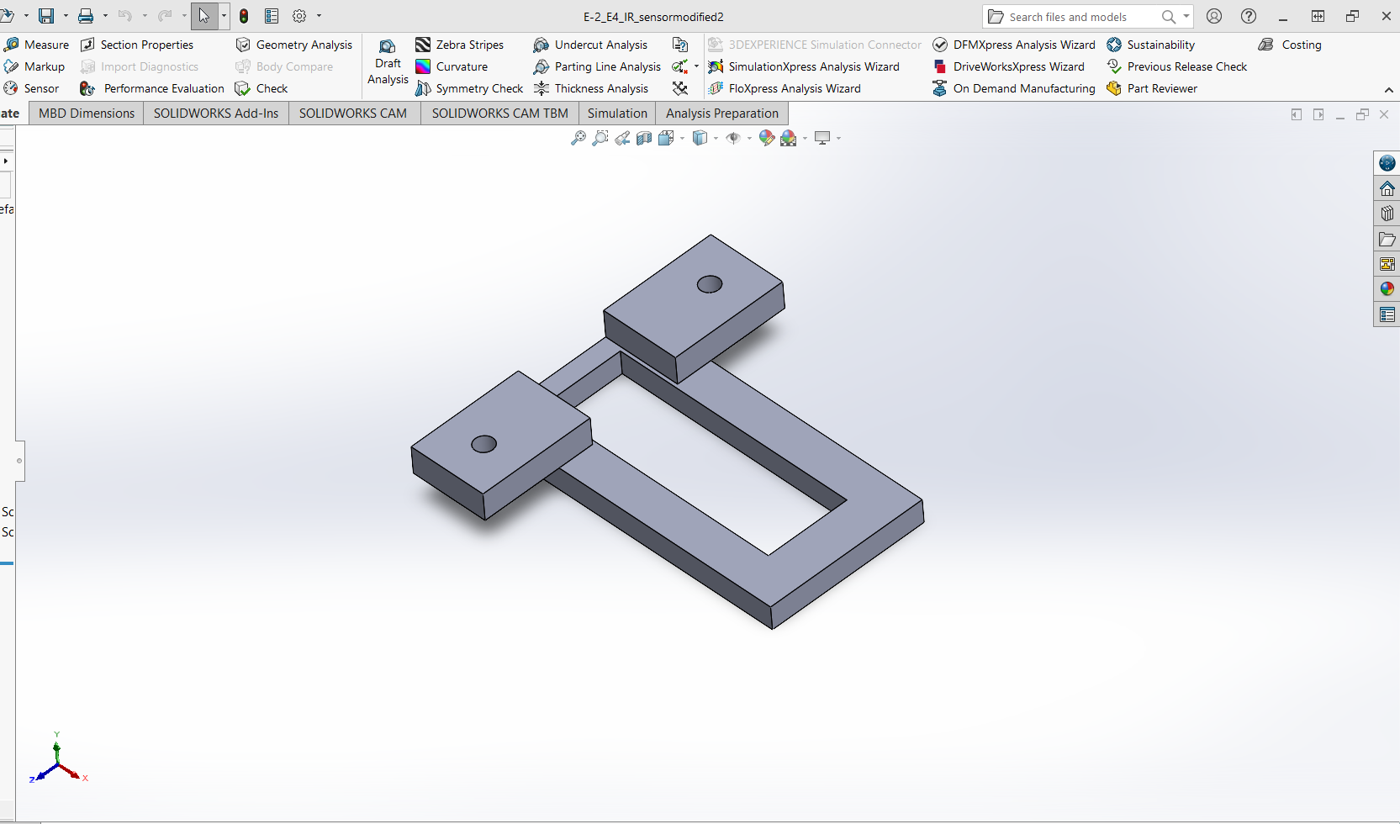
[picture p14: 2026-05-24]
CAD_Designs /CAD_Designs/IR_sensor_holder .png

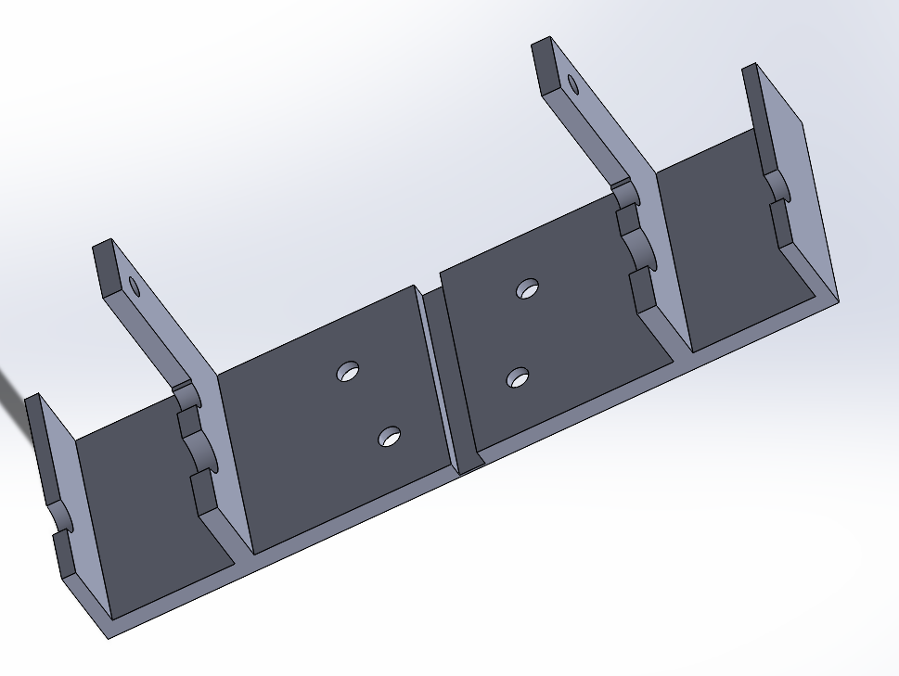
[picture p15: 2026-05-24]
CAD_Designs /CAD_Designs/GearMotor_Holder/Bottom_Part.png

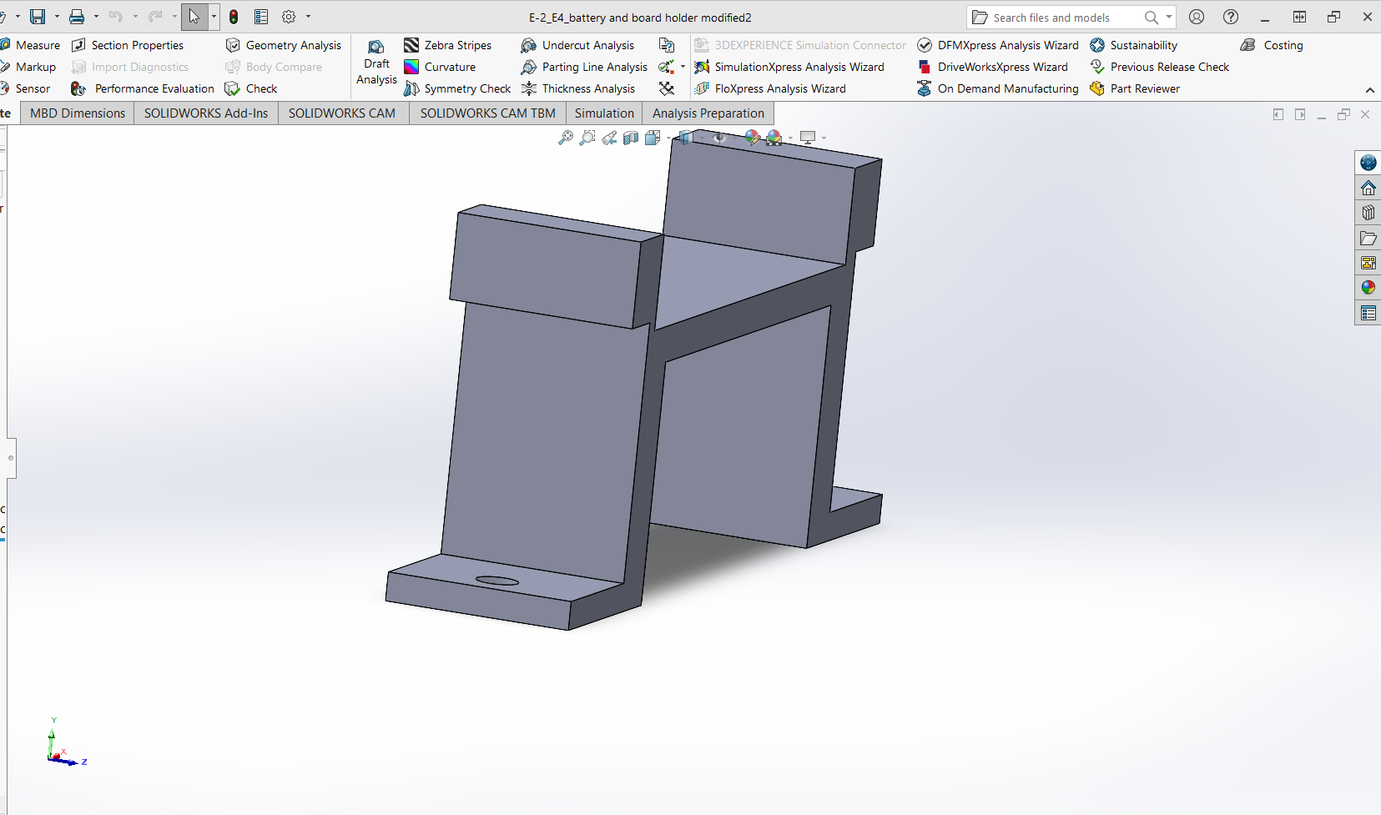
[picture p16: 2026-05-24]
CAD_Designs /CAD_Designs/battery_and_breadboard_holder .png

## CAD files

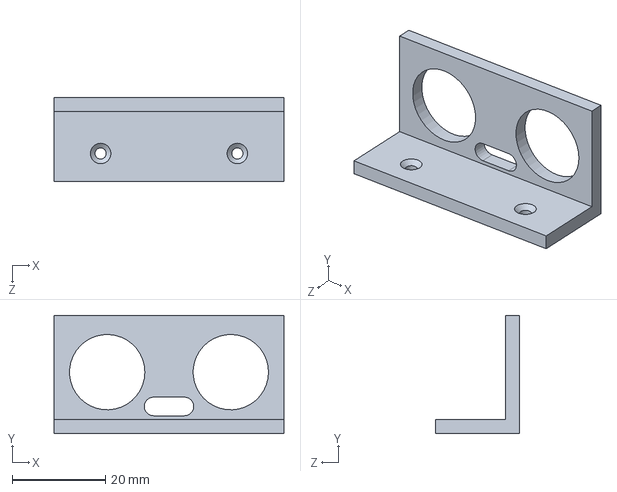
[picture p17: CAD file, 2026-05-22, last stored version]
CAD_Designs /CAD_Designs/Ultra_Sonic_Sensor_E-2_E4.SLDPRT
49.3 x 25.3 x 18.0 mm

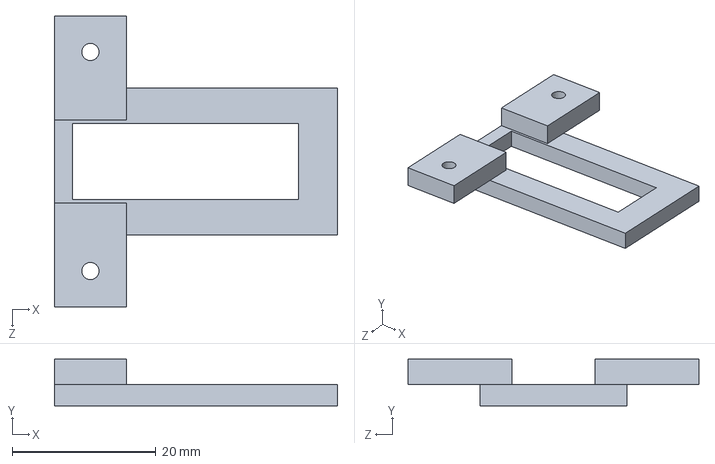
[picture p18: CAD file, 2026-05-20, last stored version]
CAD_Designs /CAD_Designs/E-2_E4_IR_sensormodified2.SLDPRT
39.4 x 6.50 x 40.5 mm

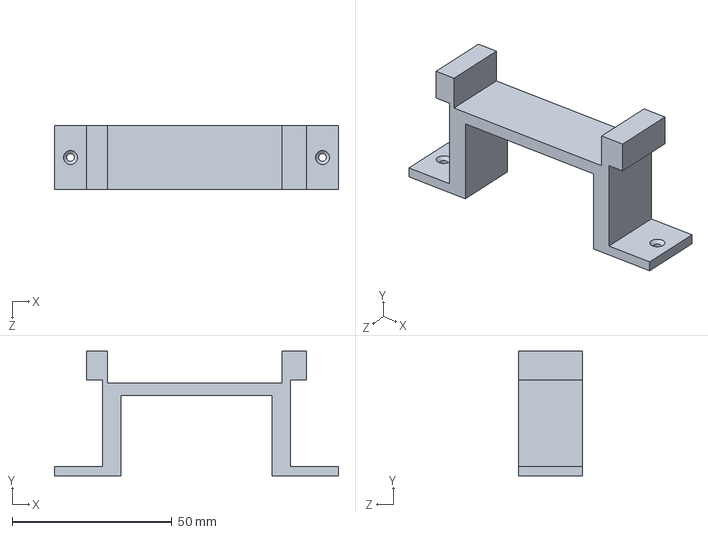
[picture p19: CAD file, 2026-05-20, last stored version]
CAD_Designs /CAD_Designs/E-2_E4_battery and board holder modified2.SLDPRT
88.8 x 39.0 x 20.0 mm

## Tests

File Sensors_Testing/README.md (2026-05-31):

## Sensor and motor testing.

This folder contains the individual test programs used to verify the correct operation of each sensor and actuator before integrating them into the full autonomous robot system.Testing each component separately helps identify wiring issues, incorrect pin mappings, faulty sensors, or logic errors early in the development process.

## Components tested individually 
-> Two IR sensors

-> Two gear motors

-> Two ultrasonic sensors

## power setup 

The system is powered using a 9V battery with a slide switch for power control.

The system powers on when the switch is closed.

The purpose of this testing is to identify and eliminate bugs or issues related to each individual sensor and component before integrating the complete system.

## Repository Structure

| Folder/File Name | Description |
|---|---|
| GearMotor | Contains code and pin connections for gear motors |
| IR_Sensor | Contains IR sensor code and pin mapping |
| Ultra_Sonic_Sensor | Contains ultrasonic sensor code and pin mappings  |
| README.md | Documentation describing sensor and motor setup |

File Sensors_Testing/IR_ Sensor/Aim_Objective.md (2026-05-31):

## Track Detection

Battery-powered system with a slide switch.

Detect the position of the track.

Sensor detection results are displayed on the Arduino Serial Monitor.

 ## IR Sensor Reading

LOW (0) when detecting black track

HIGH (1) when detecting white surface

 ## Typical arrangement

Left sensor sees white

Right sensor sees black

Robot corrects direction

## BILL OF MATERIALS

- Arduino Uno -> 1

- IR Sensor -> 2

- 9V Battery -> 1   

- Sliderswitch -> 1

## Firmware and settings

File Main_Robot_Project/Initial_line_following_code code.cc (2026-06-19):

const int leftSensor = 8;
const int rightSensor = 7;

// =========================
// L298N PINS
// =========================
const int ENA = 6;
const int IN1 = 3;
const int IN2 = 2;
const int ENB = 5;
const int IN3 = 12;
const int IN4 = 13;

// =========================
// SPEED SETTINGS
// =========================
const int forwardSpeed = 180;
const int turnSpeed = 165;
const int slowSpeed = 20;
const int searchSpeed = 90;

// 0 = straight
// 1 = left
// 2 = right
int lastDirection = 0;

void setup() {
  // Increase PWM frequency on D5 and D6
  TCCR0B = TCCR0B & B11111000 | B00000010;
  
  pinMode(leftSensor, INPUT);
  pinMode(rightSensor, INPUT);
  pinMode(ENA, OUTPUT);
  pinMode(IN1, OUTPUT);
  pinMode(IN2, OUTPUT);
  pinMode(ENB, OUTPUT);
  pinMode(IN3, OUTPUT);
  pinMode(IN4, OUTPUT);
  
  Serial.begin(9600);
  stopMotors();
}

// =========================
// MOTOR FUNCTIONS
// =========================
void moveForward() {
  digitalWrite(IN1, LOW);
  digitalWrite(IN2, HIGH);
  digitalWrite(IN3, HIGH);
  digitalWrite(IN4, LOW);
  analogWrite(ENA, forwardSpeed);
  analogWrite(ENB, forwardSpeed);
}

void turnLeft() {
  // Left wheel slower
  // Right wheel faster
  digitalWrite(IN1, LOW);
  digitalWrite(IN2, HIGH);
  digitalWrite(IN3, HIGH);
  digitalWrite(IN4, LOW);
  analogWrite(ENB, slowSpeed);
  analogWrite(ENA, turnSpeed);
}

void turnRight() {
  // Left wheel faster
  // Right wheel slower
  digitalWrite(IN1, LOW);
  digitalWrite(IN2, HIGH);
  digitalWrite(IN3, HIGH);
  digitalWrite(IN4, LOW);
  analogWrite(ENB, turnSpeed);
  analogWrite(ENA, slowSpeed);
}

void searchLeft() {
  digitalWrite(IN1, HIGH);
  digitalWrite(IN2, LOW);
  digitalWrite(IN3, HIGH);
  digitalWrite(IN4, LOW);
  analogWrite(ENA, searchSpeed);
  analogWrite(ENB, searchSpeed);
}

void searchRight() {
  digitalWrite(IN1, LOW);
  digitalWrite(IN2, HIGH);
  digitalWrite(IN3, LOW);
  digitalWrite(IN4, HIGH);
  analogWrite(ENA, searchSpeed);
  analogWrite(ENB, searchSpeed);
}

void stopMotors() {
  analogWrite(ENA, 0);
  analogWrite(ENB, 0);
}

// =========================
// MAIN LOOP
// =========================
void loop() {
  int L = digitalRead(leftSensor);
  int R = digitalRead(rightSensor);
  
  Serial.print("Left = ");
  Serial.print(L);
  Serial.print(" | Right = ");
  Serial.println(R);
  
  // ===================================
  // SENSOR LOGIC
  // ===================================
  // Black line = 1
  // White area = 0
  // L = 0, R = 0 -> Forward
  // L = 1, R = 0 -> Turn Left
  // L = 0, R = 1 -> Turn Right
  // L = 1, R = 1 -> Search last direction
  
  if (L == 1 && R == 1) {
    moveForward();
    Serial.println("Forward");
  } 
  else if (L == 1 && R == 0) {
    turnLeft();
    lastDirection = 1;
    Serial.println("Turn Left");
  } 
  else if (L == 0 && R == 1) {
    turnRight();
    lastDirection = 2;
    Serial.println("Turn Right");
  } 
  else if (L == 1 && R == 1) {
    if (lastDirection == 1) {
      searchLeft();
      Serial.println("Search Left");
    } 
    else if (lastDirection == 2) {
      searchRight();
      Serial.println("Search Right");
    } 
    else {
      moveForward();
      Serial.println("Search Forward");
    }
  }
  
  delay(10);
}

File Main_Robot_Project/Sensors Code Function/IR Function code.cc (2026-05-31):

// Digital input pin connected to IR sensors
int leftSensor = 8;
int rightSensor = 7;

// ==========================
// Function: detectTrack()
// Reads both sensors and prints
// the detected track position
// ==========================
void detectTrack() {

  // Read sensor values
  // LOW  = Black line detected
  // HIGH = White surface detected
  int leftValue = digitalRead(leftSensor);
  int rightValue = digitalRead(rightSensor);

  // Both sensors detect the black line
  if (leftValue == LOW && rightValue == LOW) {
    Serial.println("Track Centered");
  }

  // Left sensor detects the line and Right sensor sees white
  else if (leftValue == LOW && rightValue == HIGH) {
    Serial.println("Move Left");
  }

  // Right sensor detects the line and Left sensor sees white
  else if (leftValue == HIGH && rightValue == LOW) {
    Serial.println("Move Right");
  }

  // Neither sensor detects the line
  else {
    Serial.println("Track Lost");
  }
}

// ==========================
// Setup
// Runs once when Arduino starts
// ==========================
void setup() {

  // Configure sensor pins as inputs
  pinMode(leftSensor, INPUT);
  pinMode(rightSensor, INPUT);

  // Start serial communication
  // Used to display sensor status
  Serial.begin(9600);
}

// ==========================
// Main Loop
// Runs continuously
// ==========================
void loop() {

  // Call track detection function
  detectTrack();

  // Small delay for readable output
  delay(200);
}

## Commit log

2026-05-16 Use Case Diagram for Autonomous Vehicles
2026-05-18 Add files via upload
    The use case diagram of autonomous vehicle.
2026-05-20 Update README.md
    Add README for prototype holders
2026-05-20 Add files via upload
    Uploaded battery and bread holder
    [E-2_E4_battery and board holder modified2.SLDPRT]
2026-05-20 Add files via upload
    uploaded IR sensor
    [E-2_E4_IR_sensormodified2.SLDPRT]
2026-05-21 TinkerCad Circuit Diagram
    Tinkercad Circuit Diagram for the robot involving an Arduino board, 9v battery, 2-Gearmotor, 2-IR sensor, motor driver, and 2-ultra sonic sensor.
2026-05-21 TinkerCad Circuit Diagram
    Tinkercad Circuit Diagram for the robot involving an Arduino board, 9v battery, 2-Gearmotor, 2-IR sensor, motor driver, and 2-ultra sonic sensor,
2026-05-21 Rename image.png to TinkerCad Circuit Diagram.png
2026-05-24 Add files via upload
    uploaded IR sensor holder
2026-05-24 Add files via upload
    uploaded battery and bread board holder
2026-05-24 Requirements Diagram
    The Requirements Diagram represents the functional, hardware, and behavioral requirements of the Autonomous Vehicle System developed for this project. The system is designed to autonomously follow a predefined track, detect obstacles, avoid collisions, and perform intelligent navigation tasks using embedded hardware components and sensor-based decision making.
2026-05-24 Sequence Diagram
    The Sequence Diagram models the dynamic interaction and communication flow between the hardware and control components of the Autonomous Vehicle System during autonomous driving and obstacle avoidance operations. The diagram describes how sensors, controllers, and actuators interact over time to achieve autonomous navigation behavior.
2026-05-24 Ultra Sonic Sensor Holder
    Mounting the Ultra Sonic Sensors to the Chassis
2026-05-24 Add README for Sensors Testing
    Document the testing process for individual components.
2026-05-24 Add Aim and Bill of Materials for IR Sensor Project
    Document the aim and components of the IR sensor system for track detection.
2026-05-24 TinkerCad_Diagram
    Simulating the IR sensor test in TInkerCad
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2026-05-24 Create Aim_Objective documentation for sensor testing
    Added documentation for obstacle detection system including detection threshold and bill of materials.
2026-05-24 Add ultrasonic sensor obstacle detection code
    This code implements an ultrasonic sensor obstacle detection system using two HC-SR04 sensors. It reads distances from both sensors and prints whether an obstacle is detected based on a defined thres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
2026-05-24 Create Aim_Objective documentation for GearMotor
    Added documentation for GearMotor Aim_Objective including system behavior and bill of materials.
2026-05-24 Add motor control code for dual DC motors
    This code controls two DC motors using an Arduino UNO and L293D motor driver. It sets up the motor connections and implements a loop that drives both motors forward for 3 seconds, then stops for 2 se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
2026-05-24 Enhance Aim_Objective with robot specifications
    Expanded the Aim_Objective file to include detailed specifications for the track-following robot, including system behavior and a bill of materials.
2026-05-24 Simulating The Robot system in TinkerCad
    Simulating the self-driving robot system in Tinkercad.
    The simulation demonstrates:
    - Line tracking using IR sensors
    - Obstacle detection using ultrasonic sensors
    - Motor control using the motor driver
    - Battery-powered operation with a slide switch
    The robot moves forward when it is correctly positioned on the track and no obstacle is detected.
    If the robot deviates from the track, it automatically self-corrects its position and continues moving.
    If an obstacle is detected within the threshold distance, the robot stops.
2026-05-24 Add design description for GearMotor holder
    Added a description for the GearMotor holder design, detailing its components and functionality.
2026-05-24 Bottom Part Motor Holder
2026-05-24 Real world Assembly part
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2026-05-28 Modify pin connections for IR sensors
    Updated IR sensor pin connections for Arduino Uno.
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2026-05-28 Add Pin Connections for Motors, Sensors, and IR
2026-05-31 Changed the signal pin from 6 and 9 to 7 and 8
2026-05-31 Revise pin connections for left and right gear motors
    1. Enable1&2 is connecte to pin6
    2. Enable3&4 is connected to pin 9
    3. The negative terminals of two gear motor should be connected to the output pin of Drivemotor.
2026-05-31 Create README.md for tinkercad
    I am going to upload the tinker cad of motordriver there
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2026-05-31 Update README with Tinkercad Motor Driver test details
    Added details about the Tinkercad Motor Driver test setup, including components and connections.
2026-05-31 Document motor driver test setup and functionality
    Added detailed testing information for the motor driver setup.
2026-05-31 Add motor driver code for simultaneous motor control
    This code controls two DC motors using an Arduino UNO and L293D motor driver. It sets up the motor pins, drives both motors forward for 3 seconds, stops for 2 seconds, and repeats this cycle.
2026-05-31 Document motor driver pin connections
    Added detailed pin connection information for the motor driver and Arduino Uno.
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2026-05-31 Add files via upload
    Modified TinkerCAD diagrams the enable pins were changed from A1 and A2 to PWM pins and the IR sensor pins were also modified as well.
2026-05-31 Create =
    A new folder was created to store the circuit wiring diagrams the initial and new.
2026-05-31 Rename Main_Robot_Project/Initial TinkerCad_Diagram.png to Main_Robot_Project/Tinkercad_circuitwiring/Initial TinkerCad_Diagram.png
    Move Initial TinkerCad diagram to Wiring_Diagrams folder
2026-05-31 Rename Main_Robot_Project/modifiedtinkercaddiagram.png to Main_Robot_Project/Tinkercad_circuitwiring/modifiedtinkercaddiagram.png
    Move mofified TinkerCad diagram to Wiring_Diagrams folder
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2026-05-31 Fix formatting in Bill of Materials section
2026-06-17 Update Trigger pin for second Ultra Sonic sensor
2026-06-17 Change trig2 pin from 5 to 9 for sensor 2
2026-06-19 Swap IN1 and IN2 pins and adjust speed settings
    Updated motor control logic and speed settings for improved maneuverability.
2026-07-01 Implement PID line following with obstacle avoidance
    We are successfully!
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2026-07-14 Update power supply description in README
    change the battery supply and the button type
2026-07-14 Rename use case diagram file to 'Usecase Diagram.png'
2026-07-14 Update README with new use case diagram and final diagram
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
